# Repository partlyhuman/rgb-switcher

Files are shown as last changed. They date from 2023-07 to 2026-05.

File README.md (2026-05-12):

# OveRGBkill

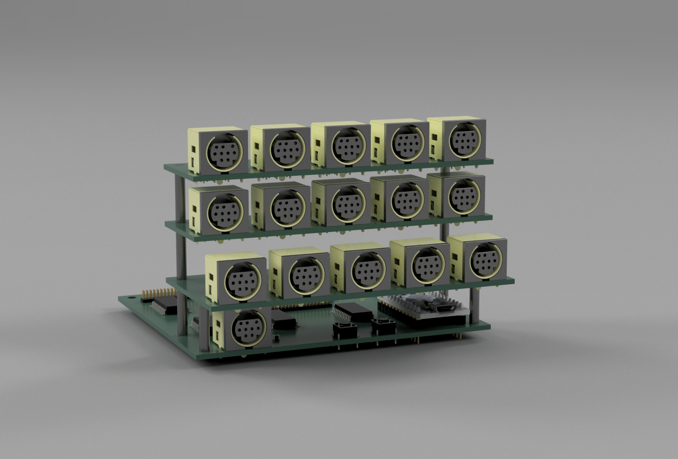
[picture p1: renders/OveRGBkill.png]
Render


*OveRGBkill* is an expandable analog RGB video switcher using common components.

# Warning

This is all hobbyist hardware and software, and could potentially damage your precious retro gaming equipment. It is provided "as is", without warranty of any kind, express or implied, including but not limited to the warranties of merchantability, fitness for a particular purpose, and noninfringement.

Be sure to scroll down for important notes integrating this into a real world AV system.

## Features

* Modular, up to 15 RGB inputs
* Standard Megadrive (MD2) style Mini-DIN 9 connectors
* Very compact, powered via USB 5V
* Sense and automatically switch to active input
* Routes R, G, B, and Composite video, Stereo audio Left, Right, Ground, and +5V. Other pins are not connected
* Extremely low cost per assembly for [parts](https://www.digikey.ca/en/mylists/list/I2IMYMPBML) (~US$20) and <100mm 4-layer PCB (~US$7)

Pairs well with a [HD Retrovision Genesis cable](https://www.hdretrovision.com/genesis) or my inferior [RGB-Component transcoder](https://github.com/partlyhuman/rgb-yuv-transcoder) if you have a TV with component input.

## Integrations

Some notes on how to wire your consoles for RGB output, from my experience. A good starting point is [RetroRGB](https://www.retrorgb.com/systems.html).

### RGB-capable systems

For systems that are already RGB capable but don't have an MD2 connector, such as Saturn, SNES, N64, Playstation 1/2, etc., I'll make an MD2 connector out of a SCART connector:

* Purchase an RGB-capable SCART connector
* Splice off the SCART head
* Disassemble the SCART head and use a SCART pinout to note which colour wire has which purpose. Many I've bought from AliExpress have this pinout *but you MUST verify for yourself* using a continuity tester
	* Yellow — Composite
	* Orange — Red
	* Green — Green
	* Blue — Blue
	* Brown — +5V
	* Purple — GND
	* Black — Audio GND
	* White — Audio Left
	* Red — Audio Right
* Use a Mini DIN-9 breakout PCB with a female Mini DIN-9 socket (the MD-90SM is ubiquitous)
	* For simple applications, something like [MobiusStripTech's breakout board](https://oshpark.com/shared_projects/amKj4zix) is great
 	* An even more compact option is [DB Electronics' breakout board](https://github.com/db-electronics/MD-90SM-breakout-kicad/releases/tag/0.1), specifically version 0.1.
	* To include AC coupling capacitors, voltage dividers and/or mono expansion, use the [breakout PCB](pcb/md2-rgb/) in this repository!
* A 3d printable shell finishes the cable. On one end you have a console-specific connector, on the other end you have a female MD2 connector, and use a straight Mini DIN-9 cable to wire this to your switcher.
 	* For the MobiusStripTech breakout, [this case](https://www.thingiverse.com/thing:3048576) works well
  	* If you use the DB Electronics breakout, I've [remixed the above case](https://www.thingiverse.com/thing:7306404)
   	* If using our breakout PCB, an accompanying shell is [here](3dp/md2-rgb), based on [sensorslot's project box template](https://github.com/SensorsIot/Project-Box-Templates/)

### SNES/SFC

Needs 220μF coupling capacitors on RGBC, use the  [breakout PCB](pcb/md2-rgb/) in this repository

### PS1/PS2

Needs 220μF coupling capacitors on RGBC, use the  [breakout PCB](pcb/md2-rgb/) in this repository

### Sega Genesis/Megadrive

Seems to use a much higher voltage, incorporate a voltage divider of around 1:2 on RGBC (for example R1=33Ω, R2=75Ω), using the breakout PCB or the customizable daughterboard.

### Arcade superguns

Many of these use 5V TTL CSYNC, incorporate a voltage divider of around 1:4  on C using the breakout PCB or the customizable daughterboard.

### Others

In general, if you have RGB modded your system, well designed mods will already use the correct voltages, AC coupling, and impedances, and I found that my RGB-modded PC Engine (doujindance) and NESRGB needed no further modification.

**Note** In fact it probably never hurts to add 220μF coupling capacitors on all inputs. This could be incorporated into future revisions of the daughterboard.

## Build considerations

### Daughterboard choice

Use the simple daughterboard if your inputs are standardized: if they're all AC-coupled (0 DC bias), with 75Ω impedance, and 0.7V peak-peak at 100 IRE.

You may use the customizable daughterboard to adjust voltages with voltage dividers built into the board. Or it may be more convenient to build these into your cables. It's your choice.

Of course you can also mix and match.

### Impedance Matching

A video buffer is integrated into the current revision of the hardware so that the switcher has typical 75Ω impedance.

### Cables

In the MD2 pinout, ground is carried over the shielding of a cable. Therefore, all mini-DIN 9 cables used with this must be shielded. Some cheap cables you may find on AliExpress skimp out on this, and it's not called out, so beware. Use a multimeter to check continuity between the metal outer ring of each end of the cable to verify you have shielded cables.

I can verify that (at the time I purchased them) these cables from "wg cable store" are shielded: [AliExpress](https://www.aliexpress.com/item/1005004607170871.html)

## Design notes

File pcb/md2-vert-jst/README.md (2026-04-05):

## Parts:

The normal DIN vertical connectors sadly top out at Mini DIN-8, but I found this Mini DIN-9:

https://www.aliexpress.com/item/1005007621768448.html (9Pin MDC-9-04 variant)

The connector is JST-ZH (1.5mm pitch), 8 pin, which is easier to find, but here's one seller:

https://www.aliexpress.com/item/1005001649158434.html (ZH 1.5MM, 8P, 30CM variant)

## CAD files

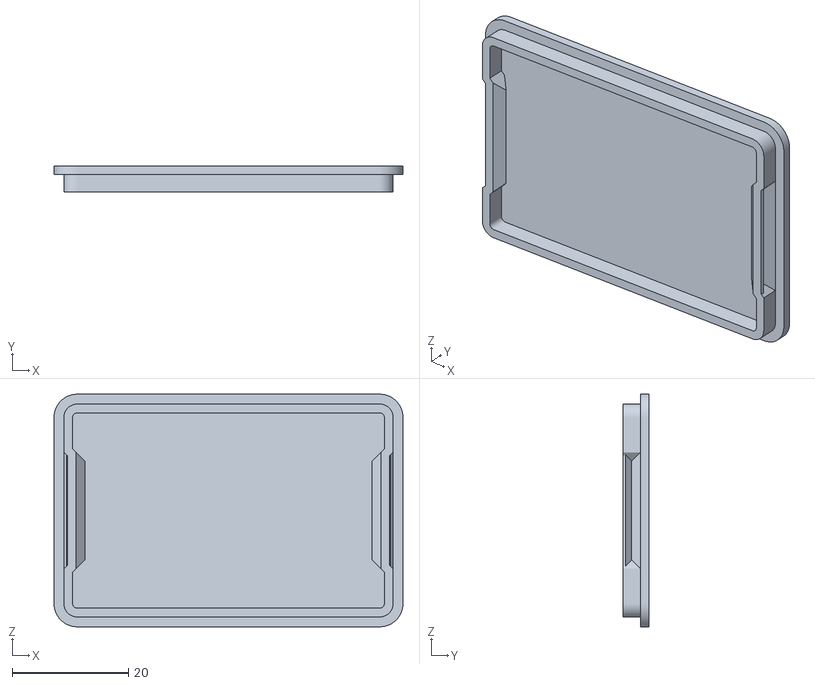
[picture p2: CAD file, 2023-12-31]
3dp/md2-rgb/md5-pcb-enclosure_lid.stl
60.0 x 4.50 x 40.0

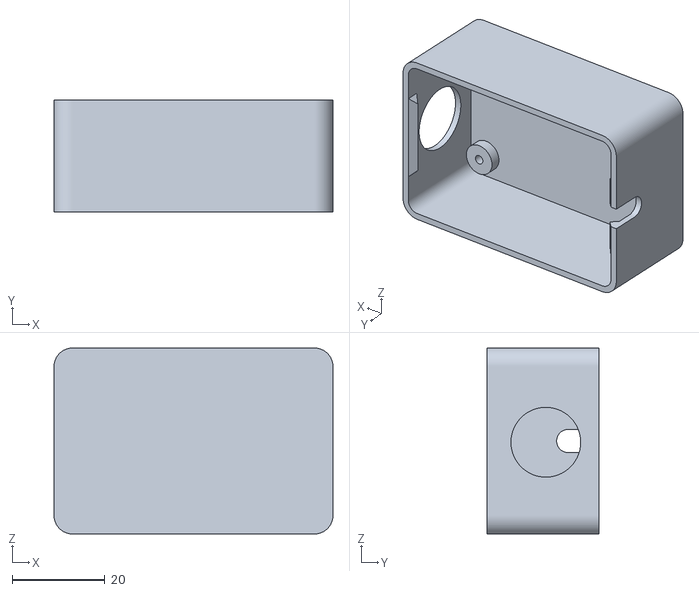
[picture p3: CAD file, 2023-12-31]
3dp/md2-rgb/md5-pcb-enclosure_box.stl
60.0 x 24.0 x 40.0

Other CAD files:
3dp/md2-rgb/MD2RGB case v6.f3z

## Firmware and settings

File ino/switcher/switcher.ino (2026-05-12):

#define CHANNELS 15

// 5v VIN_ADC selector
#define VIN_A0 10
#define VIN_A1 16
#define VIN_A2 14
#define VIN_A3 15
#define VIN_ADC A0
// out of 1024, fraction of VCC
// about 3V at 4.9V
#define TRIGGER_V 620

// video mux
#define VID_A0 6
#define VID_A1 7
#define VID_A2 8
#define VID_A3 9
// audio mux
#define AUD_A0 5
#define AUD_A1 4
#define AUD_A2 3
#define AUD_A3 2

// Look up the address of a channel here
const uint8_t AUDIO_MAP[] {8,9,10,11,12,13,14,15,7,6,5,4,3,2,1,0};

const int ALL_OFF = -1;
static int currentChannel = ALL_OFF;

void flash(uint8_t pin, int times = 1, unsigned long onfor = 100, unsigned long offfor = 50) {
  for (int i = 0; i < times; i++) {
    digitalWrite(pin, HIGH);
    delay(onfor);
    digitalWrite(pin, LOW);
    delay(offfor);
  }
}

void setup() {
  Serial.begin(115200);
  Serial.println("BOOTED");

  pinMode(VIN_A0, OUTPUT);
  pinMode(VIN_A1, OUTPUT);
  pinMode(VIN_A2, OUTPUT);
  pinMode(VIN_A3, OUTPUT);

  pinMode(VID_A0, OUTPUT);
  pinMode(VID_A1, OUTPUT);
  pinMode(VID_A2, OUTPUT);
  pinMode(VID_A3, OUTPUT);

  pinMode(AUD_A0, OUTPUT);
  pinMode(AUD_A1, OUTPUT);
  pinMode(AUD_A2, OUTPUT);
  pinMode(AUD_A3, OUTPUT);

  pinMode(VIN_ADC, INPUT);
  // pinMode(SW1, INPUT_PULLUP);
  // pinMode(SW2, INPUT_PULLUP);

  pinMode(LED_BUILTIN, OUTPUT);
  // pinMode(LED_BUILTIN_RX, OUTPUT);
  // pinMode(LED_BUILTIN_TX, OUTPUT);

  flash(LED_BUILTIN, 3);
  // flash(LED_BUILTIN_RX);
  // flash(LED_BUILTIN_TX);
}

void setSenseChannel(int channel) {
  digitalWrite(VIN_A0, (channel & 0b0001) > 0);
  digitalWrite(VIN_A1, (channel & 0b0010) > 0);
  digitalWrite(VIN_A2, (channel & 0b0100) > 0);
  digitalWrite(VIN_A3, (channel & 0b1000) > 0);
  delay(10);
}

int senseChannel(int channel) {
  setSenseChannel(channel);
  return analogRead(VIN_ADC);
}

// returns most active channel
int sweepChannels() {
  for (int i = 0; i < CHANNELS; i++) {
    int voltage = senseChannel(i);
    if (voltage > 0) {
      Serial.print(i);
      Serial.print(" ");
      Serial.println(voltage);
    }
    // For now the first one that's on is on
    if (voltage > TRIGGER_V) {
      return i;
    }
  }
  return ALL_OFF;
}

void setChannel(int channel) {
  if (channel < 0) return;

  digitalWrite(VID_A0, (channel & 0b0001) > 0);
  digitalWrite(VID_A1, (channel & 0b0010) > 0);
  digitalWrite(VID_A2, (channel & 0b0100) > 0);
  digitalWrite(VID_A3, (channel & 0b1000) > 0);

  uint8_t achannel = AUDIO_MAP[channel];
  Serial.print(channel);
  Serial.print(" -> audio channel ");
  Serial.println(achannel);
  digitalWrite(AUD_A0, (achannel & 0b0001) > 0);
  digitalWrite(AUD_A1, (achannel & 0b0010) > 0);
  digitalWrite(AUD_A2, (achannel & 0b0100) > 0);
  digitalWrite(AUD_A3, (achannel & 0b1000) > 0);
}

void loop() {
  bool off = currentChannel == ALL_OFF;
  delay(off ? 1000 : 4000);
  if (off) {
    int newChannel = sweepChannels();
    setChannel(newChannel);
    if (newChannel != currentChannel) {
      flash(LED_BUILTIN);
      Serial.print("Channel = ");
      Serial.println(newChannel);
    }
    currentChannel = newChannel;
  } else {
    // we only need to check if the current channel turned off (should we make this test more than once?)
    if (senseChannel(currentChannel) < TRIGGER_V) {
      currentChannel = ALL_OFF;
      Serial.println("OFF");
    }
  }
}

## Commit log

2023-02-04 init daughterboard project
    [switcher-input-daughterboard.kicad_pcb, switcher-input-daughterboard.kicad_sch, switcher-input-daughterboard.sch]
2023-02-04 v0 of input daughterboard
    [switcher-input-daughterboard-B_Mask.gbr, switcher-input-daughterboard-B_Paste.gbr, switcher-input-daughterboard-B_Silkscreen.gbr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]
2023-02-05 seeing if 15 inputs can be routed, used freerouter but pcb only has demuxers and headers
    [switcher-auto.kicad_pcb, switcher-auto.kicad_sch, switcher-auto.sch]
2023-03-17 autorouting 2layer switcher
    [switcher-auto.kicad_pcb, switcher-auto.kicad_sch, switcher-input-daughterboard.kicad_sch]
2023-04-07 WIP routing as 4 layers with new connector organization
    [daughterboard.kicad_sch, switcher-auto.kicad_pcb, switcher-auto.kicad_sch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]
2023-04-09 Routing pt 2
    [daughterboard.kicad_sch, switcher-auto.kicad_pcb, switcher-auto.kicad_sch]
2023-04-09 Finish routing, not done with daughterboard changes
    [switcher-auto.kicad_pcb, switcher-auto.kicad_sch]
2023-04-09 finish routing?
    [daughterboard.kicad_sch, switcher-auto.kicad_pcb]
2023-04-09 decouple every mux
    [switcher-auto.kicad_pcb, switcher-auto.kicad_sch]
2023-04-09 Add notes for fab
    [switcher-auto.kicad_pcb]
2023-04-11 mounting holes should be M3
    [switcher-auto.kicad_pcb]
2023-04-11 Remove silkscreens, passing DRC
    [switcher-auto.kicad_pcb]
2023-05-23 Finishing routing
    [switcher-auto.kicad_pcb, switcher-auto.kicad_sch]
2023-05-23 Passing DRC
    [switcher-auto.kicad_pcb]
2023-05-23 VCC pour
    [switcher-auto.kicad_pcb]
2023-05-23 Hooks up V sense muxer
    [switcher-auto.kicad_pcb, switcher-auto.kicad_sch]
2023-05-23 Consolidate ports on rear
    [switcher-auto.kicad_pcb]
2023-05-23 minor twiddles
    [switcher-auto.kicad_pcb]
2023-06-12 Adds daughterboard with adjustment options
    [daughterboard.kicad_sch, switcher-auto.kicad_pcb, switcher-auto.kicad_sch]
2023-06-12 Use 4-point mounting on adjustable daughterboards
    [switcher-auto.kicad_pcb]
2023-06-12 Adds RGB breakout board standalone
    [daughterboard.kicad_sch, md2-rgb.kicad_pcb, md2-rgb.kicad_sch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]
2023-07-25 Previous changes? Looks like I switched 3d models
    [daughterboard.kicad_sch, md2-rgb.kicad_pcb]
2023-07-25 MD2 adapter - make pads a bit wider for hand soldering
    [md2-rgb.kicad_pcb]
2023-07-25 Add gerbers for switcher
2023-07-25 Setting 3d model
    [switcher-auto.kicad_pcb]
2023-07-25 Switching models to STEP
    [switcher-auto.kicad_pcb]
2023-07-25 Fetching 2-layer simple daughterboard from backups
    [switcher-auto-daughterboard-simple.kicad_pcb]
2023-07-25 Adds separate pcb file for daughterboard only
    [switcher-auto-daughterboard-customizable.kicad_pcb]
2023-07-25 Add STEP renders for cad, documentation
2023-07-26 Restores hierarchical sheet
    [daughterboard.kicad_sch]
2023-07-31 Adds enclosure for MD2-RGB adapter board
    [md5-pcb-enclosure.f3z, md5-pcb-enclosure_box.stl, md5-pcb-enclosure_lid.stl]
2023-12-07 Adds FPC to RGB breakout
    [md2-rgb.kicad_pcb, md2-rgb.kicad_sch]
2023-12-09 Flips FFC
    [md2-rgb.kicad_pcb, md2-rgb.kicad_sch]
2023-12-18 Adds THS7374 video amp
    [switcher-auto.kicad_pcb, switcher-auto.kicad_sch]
2023-12-25 connects FFC to composite in, not sync
    [md2-rgb.kicad_pcb, md2-rgb.kicad_sch]
2023-12-31 Slots in RGB adapter case so you don't have to desolder to insert/remove
    [MD2RGB case v6.f3z, md5-pcb-enclosure.f3z, md5-pcb-enclosure_box.stl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]
2026-03-01 WIP dual supply audio switching
    [daughterboard.kicad_sch, switcher-auto.kicad_pcb, switcher-auto.kicad_sch]
2026-03-01 Routing checkpoint
    [switcher-auto.kicad_pcb, switcher-auto.kicad_sch]
2026-03-02 Cleared up one layer for solid ground plane
    [switcher-auto.kicad_pcb, switcher-auto.kicad_sch]
2026-03-12 RGB mod using JST and vertical DIN-9
    [md2-vert-jst.kicad_pcb, md2-vert-jst.kicad_sch]
2026-03-19 Switcher should run off 5V / RAW pin
    [md2-vert-jst.kicad_pcb, md2-vert-jst.kicad_sch, switcher-auto.kicad_pcb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]
2026-03-19 Fix VCC keepout
    [switcher-auto.kicad_pcb]
2026-05-12 Add silkscreen hints for keyed connectors
    [daughterboard.kicad_sch, switcher-auto.kicad_pcb, switcher-auto.kicad_sch]
